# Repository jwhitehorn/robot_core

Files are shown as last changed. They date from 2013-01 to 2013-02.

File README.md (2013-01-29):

## Overview

Open design for a programable real-time robotics controller.

See [Byte Code](https://github.com/jwhitehorn/robot_core/wiki/Byte-Code).

## Status

This project is in a pre-alpha state, or in other words; Robot Core is currently a rough prototype. 
With that said, it's design, function, and features will change drastically as it evolves.

## Hardware & Documentation License

Copyright (c) 2013, [Jason Whitehorn](https://github.com/jwhitehorn) released under the terms of:

[Creative Commons CC-BY-SA 3.0](http://creativecommons.org/licenses/by-sa/3.0/us/)

## Software License

Copyright (c) 2013, [Jason Whitehorn](https://github.com/jwhitehorn) 
All rights reserved.

Redistribution and use in source and binary forms, with or without modification, are permitted provided that the following conditions are met:

* Redistributions of source code must retain the above copyright notice, this list of conditions and the following disclaimer.
* Redistributions in binary form must reproduce the above copyright notice, this list of conditions and the following disclaimer in the documentation and/or other materials provided with the distribution.

THIS SOFTWARE IS PROVIDED BY THE COPYRIGHT HOLDERS AND CONTRIBUTORS "AS IS" AND ANY EXPRESS OR IMPLIED WARRANTIES, INCLUDING, BUT NOT LIMITED TO, THE IMPLIED WARRANTIES OF MERCHANTABILITY AND FITNESS FOR A PARTICULAR PURPOSE ARE DISCLAIMED. IN NO EVENT SHALL THE COPYRIGHT HOLDER OR CONTRIBUTORS BE LIABLE FOR ANY DIRECT, INDIRECT, INCIDENTAL, SPECIAL, EXEMPLARY, OR CONSEQUENTIAL DAMAGES (INCLUDING, BUT NOT LIMITED TO, PROCUREMENT OF SUBSTITUTE GOODS OR SERVICES; LOSS OF USE, DATA, OR PROFITS; OR BUSINESS INTERRUPTION) HOWEVER CAUSED AND ON ANY THEORY OF LIABILITY, WHETHER IN CONTRACT, STRICT LIABILITY, OR TORT (INCLUDING NEGLIGENCE OR OTHERWISE) ARISING IN ANY WAY OUT OF THE USE OF THIS SOFTWARE, EVEN IF ADVISED OF THE POSSIBILITY OF SUCH DAMAGE.

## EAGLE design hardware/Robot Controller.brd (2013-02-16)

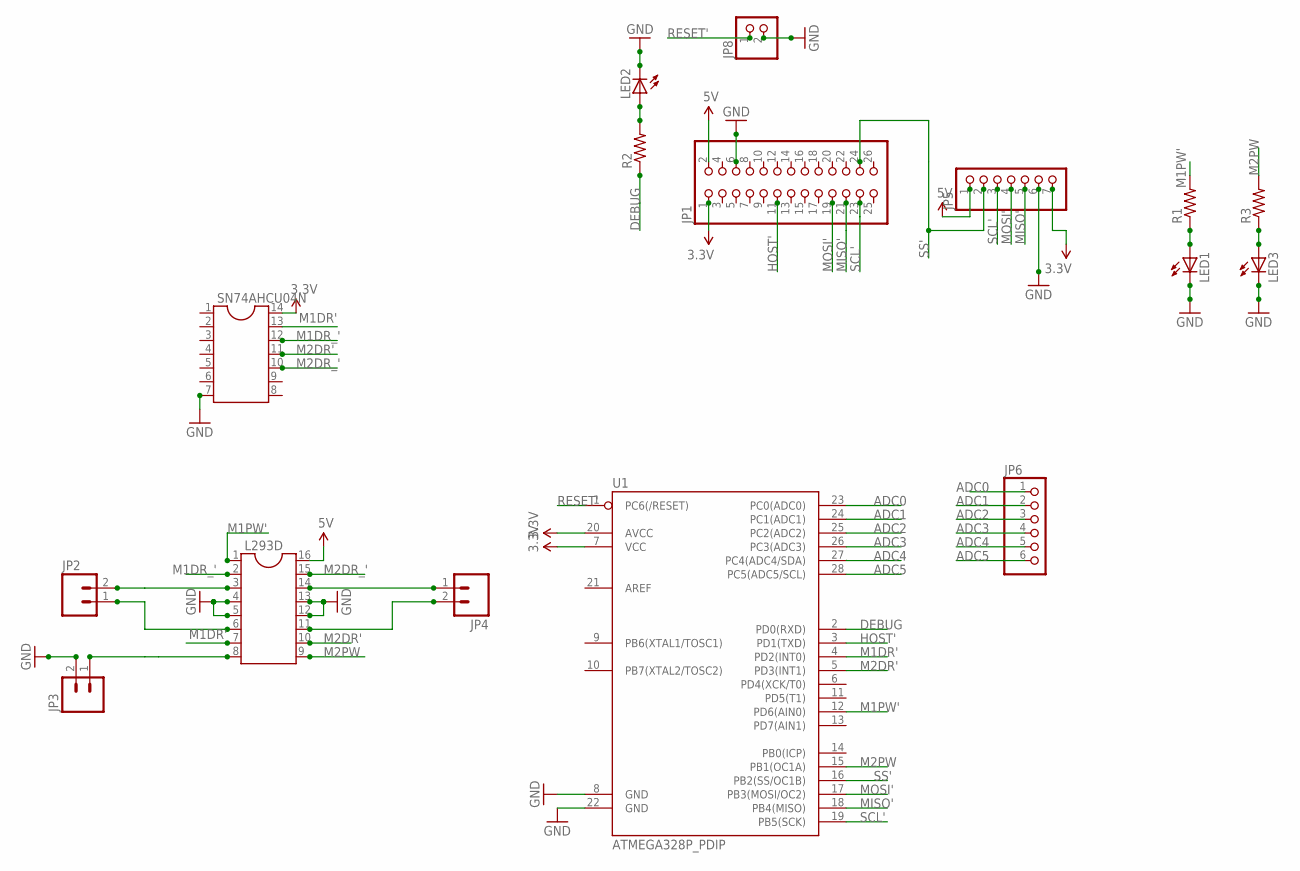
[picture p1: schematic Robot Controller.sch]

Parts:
JP1: PINHD-2X13; 2X13
JP2, JP3, JP4: M025MM; SCREWTERMINAL-5MM-2
JP5: PINHD-1X7; 1X07
JP6: PINHD-1X6; 1X06
JP8: PINHD-1X2; 1X02
L293D: DIL16S; SOCKET-16
LED1, LED2, LED3: LEDSMT1206; 1206
R1, R2, R3: R-US_R3216; R3216
SN74AHCU04N: DIL14S; SOCKET-14
U1: ATMEGA328P_PDIP; DIL28-3

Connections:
3.3V: JP1.1, JP5.7, SN74AHCU04N.14, U1.7 (VCC), U1.20 (AVCC)
5V: JP1.2, JP5.1, L293D.16
ADC0: JP6.1, U1.23 (PC0(ADC0))
ADC1: JP6.2, U1.24 (PC1(ADC1))
ADC2: JP6.3, U1.25 (PC2(ADC2))
ADC3: JP6.4, U1.26 (PC3(ADC3))
ADC4: JP6.5, U1.27 (PC4(ADC4/SDA))
ADC5: JP6.6, U1.28 (PC5(ADC5/SCL))
DEBUG: R2.1, U1.2 (PD0(RXD))
GND: JP1.6, JP3.2, JP5.6, JP8.2, L293D.4, L293D.5, L293D.12, L293D.13, LED1.C, LED2.C, LED3.C, SN74AHCU04N.7, U1.8 (GND), U1.22 (GND)
HOST': JP1.11, U1.3 (PD1(TXD))
M1DR': L293D.7, SN74AHCU04N.13, U1.4 (PD2(INT0))
M1DR_': L293D.2, SN74AHCU04N.12
M1PW': L293D.1, R1.2, U1.12 (PD6(AIN0))
M2DR': L293D.10, SN74AHCU04N.11, U1.5 (PD3(INT1))
M2DR_': L293D.15, SN74AHCU04N.10
M2PW: L293D.9, R3.2, U1.15 (PB1(OC1A))
MISO': JP1.21, JP5.5, U1.18 (PB4(MISO))
MOSI': JP1.19, JP5.4, U1.17 (PB3(MOSI/OC2))
unnamed: LED1.A, R1.1
unnamed: JP2.2, L293D.3
unnamed: JP2.1, L293D.6
unnamed: JP3.1, L293D.8
unnamed: LED3.A, R3.1
unnamed: LED2.A, R2.2
unnamed: JP4.1, L293D.14
unnamed: JP4.2, L293D.11
RESET': JP8.1, U1.1 (PC6(/RESET))
SCL': JP1.23, JP5.3, U1.19 (PB5(SCK))
SS': JP1.24, JP5.2, U1.16 (PB2(SS/OC1B))

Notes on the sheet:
SCL'
MISO'
MOSI'
RESET'
M1PW'
M2PW
M1DR'
M2DR'
M1DR_'
M2DR_'
DEBUG
HOST'
SS'
ADC0
ADC1
ADC2
ADC3
ADC4
ADC5

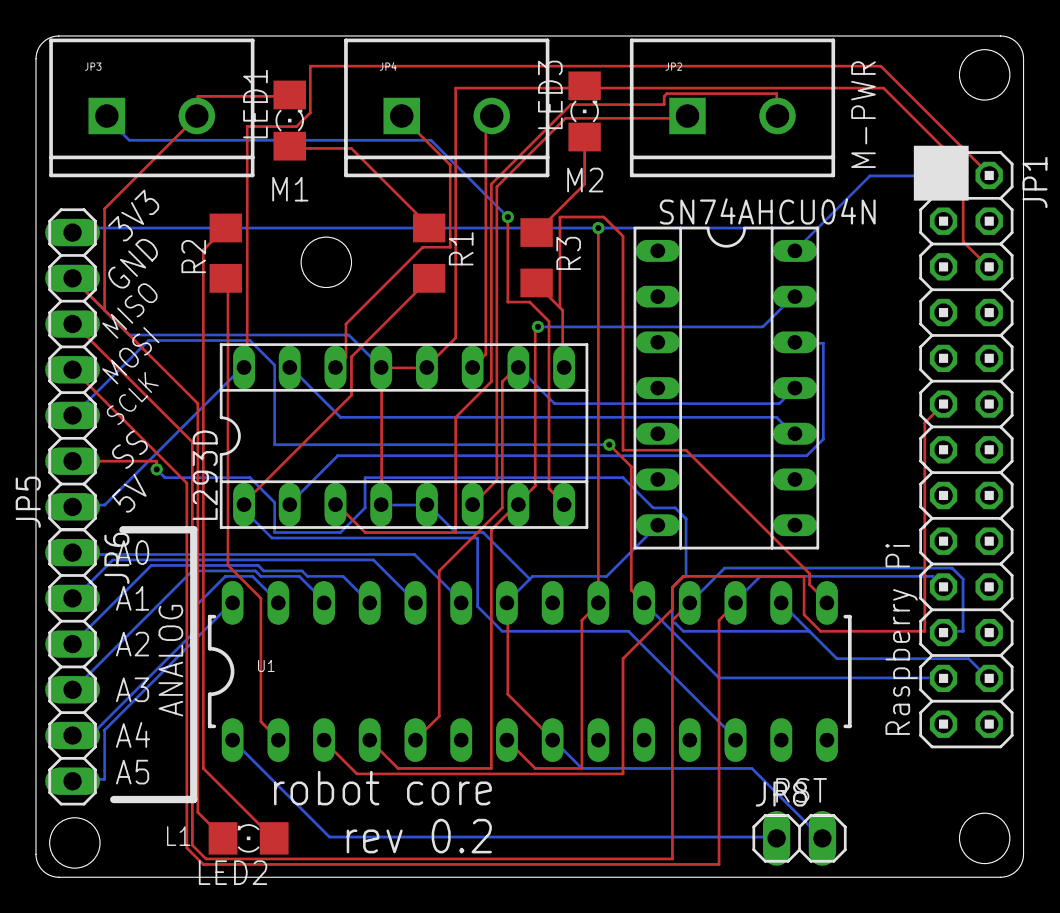
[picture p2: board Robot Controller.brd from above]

Board: 2 copper layers, 54.9 x 46.7 mm, 16 parts (0 on the bottom side), 30 nets.

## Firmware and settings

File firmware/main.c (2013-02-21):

#define F_CPU 8000000UL  // 8 MHz
#include <stdbool.h>
#include <avr/io.h>
#include <inttypes.h>
#include <avr/interrupt.h>
#include <util/delay.h>
#include "spi.h"
#include "helpers.h"

//SPI
#define CTRL_PORT   DDRB 
#define DATA_PORT   PORTB 
#define CLK_PIN     PB7 
#define DI_PIN      PB5 
#define DO_PIN      PB6 

//registers
#define REG_M1PW   0x01  //motor 1, pulse width
#define REG_M2PW   0x02  //motor 2, pulse width
#define REG_M1DR   0x03  //motor 1, direction
#define REG_M2DR   0x04  //motor 2, direction
#define ADC1       0x05  //ADC 1
#define GPIO1      0x06  //GPIO 1

//op codes
#define REGW       0x01
#define CLRH       0x02
#define RIFEQ      0x03
#define RIFLT      0x04
#define MODE       0x05
#define RIFGT      0x06


/*

Have the main run-loop of the app just poll various pins and check various registers based on
a table that the "processCommand" function esthablishes via direction of the host.

The refactored commands might look like:

REGWIFEQ w, x, y, z - writes x to register w if register y is equal to z
REGWIFLT w, x, y, z - writes x to register w if register y is less than z
REGWIFGT w, x, y, z - writes x to register w if register y is greater than z

This will mean we'll need "registers" for each GPIO & analog pin.

Later we can add timers as registers too.
  
*/


#define MAX_COMMAND_LEN 10
char command_buffer[MAX_COMMAND_LEN] = {0};
int command_length = 0;


#define MAX_TABLE_SIZE 10
char table[MAX_TABLE_SIZE][MAX_COMMAND_LEN];
int table_size = 0;


void clearBuffer(){
    command_length = 1; //since we're ignoring the first byte, just skip it and assume 0
    for(int i = 0; i != MAX_COMMAND_LEN; i++) command_buffer[i] = 0x00; //clear buffer
}

void storeCommandInTable(char *command, int length){
  if(table_size < MAX_TABLE_SIZE){
    int table_entry = table_size++;
    for(int i = 0; i != length || MAX_COMMAND_LEN; i++){
      table[table_entry][i] = command[i];
    }
  }
}

int compareRegister(int reg, int value){
  int valueRead = 0;
  if(reg == ADC1){
    uint16_t adc = ReadADC(0);
    valueRead = (adc >> 2);
  }else if(reg == GPIO1){
    valueRead = readPin(GPIO1_PIN);
  }else{
    return -2;
  } 
  if(valueRead < value){
    return -1;
  }else if(valueRead == value){
    return 0;
  }
  return 1;
}

bool processCommand(char *command, int length, bool store){
  if(length < 2) return false;    //no command is this short
  
  int op_code = command[1];  //first byte of op-code isn't implemented yet

  if(op_code == REGW){
    /*
    * REGW - Register Write - Writes byte 4 to the register specified in byte 3
    * Command length: 4 bytes
    */
    if(length >= 4){
      int reg = command[2];
      int byte = command[3];
      if(reg == 0x00){              //0x00 is undocumented, used for debugging. It echoes the received bit on the host pin.
        if(byte > 0){
          outputHigh(HOST_PIN);
        }else{
          outputLow(HOST_PIN);
        }
      }else if(reg == REG_M1PW){
        OCR0A = byte;
      }else if(reg == REG_M2PW){
        OCR1A = byte;
      }else if(reg == REG_M1DR){
        if(byte > 0){
          outputHigh(M1DR_PIN);
        }else{
          outputLow(M1DR_PIN);
        }
      }else if(reg == REG_M2DR){
        if(byte > 0){
          outputHigh(M2DR_PIN);
        }else{
          outputLow(M2DR_PIN);
        }
      }
      return true;
    }//else, wait for more bytes...
  }else if(op_code == CLRH){
    /*
    * CLRH - Clear Host Pin - Resets the host pin. E.g., it sets it low.
    * Command length: 2 bytes
    */
    outputLow(HOST_PIN);
    return true;
  }else if(op_code == RIFLT || op_code == RIFGT || op_code == RIFEQ){
    /*
    * RIFEQ x, y - raise the host pin if register x is equal to y (binary pins will have their registers either be 0x00 or 0x01)
    * RIFLT x, y - raise the host pin if register x is less than y
    * RIFGT x, y - raise the host pin if register x is greater than y
    * Command Length: 4 bytes
    */
    if(length >= 4){
      if(store){
        storeCommandInTable(command, length);
      }else{
        int reg = command[2];
        int value = command[3];
        int result = compareRegister(reg, value);
        if(op_code == RIFLT && result == -1){
          outputHigh(HOST_PIN);
        }else if(op_code == RIFGT && result == 1){
          outputHigh(HOST_PIN);
        }else if(op_code == RIFEQ && result == 0){
          outputHigh(HOST_PIN);
        }
      }
      return true;
    } 
  }else if(op_code == MODE){
    if(length >= 4){
      int reg = command[2];
      int mode = command[3];
      if(reg == GPIO1 && mode == 0x00){
        setInput(GPIO1_PIN); 
      }else if(reg == GPIO1 && mode == 0x01){
        setOutput(GPIO1_PIN);
      }
      return true;
    }
  }else{ //unknown op code
    return true; //??
  }
  return false;
}

void processCommandBuffer(){
  bool result = processCommand(command_buffer, command_length, true);
  if(result){
    clearBuffer();
  }
}

ISR(SPI_VECTOR){
  int byte = spiReceived() / 2;

  if(command_length < MAX_COMMAND_LEN){ //do not allow overflow, no command should be this long
    command_buffer[command_length++] = byte;
    processCommandBuffer();
  }else{
    clearBuffer();
  } 
}

int main(void){
  setOutput(M1PW_PIN);
  TCCR0B = 0;                     // stop timer 0
  TCCR0A = (1<<WGM00)|(1<<WGM01); // select fast pwm mode 3
  TCCR0A |= (1<<COM0A1);          //Clear OC0A on Compare Match when up-counting. Set OC0A on Compare Match when down-counting.
  OCR0A = 0x00;                   //duty cycle
  TCCR0B |= (1<<CS00);            // no prescaling

  setOutput(M2PW_PIN);
  TCCR1B = 0;
  TCCR1A = (1<<WGM00);
  TCCR1A |= (1<<COM1A1);
  OCR1A = 0x00;
  TCCR1B |= (1<<CS00);
  
  setOutput(HOST_PIN);
  outputLow(HOST_PIN);

  // Select Vref=AVcc
  ADMUX |= (1<<REFS0);
  //set prescaller to 128 and enable ADC 
  ADCSRA |= (1<<ADPS2)|(1<<ADPS1)|(1<<ADPS0)|(1<<ADEN);  

  //Setup SPI/USI
  setupSpi();

  clearBuffer();
  sei();
  
  setOutput(M1DR_PIN);
  outputLow(M1DR_PIN);
  setOutput(M2DR_PIN);
  outputLow(M2DR_PIN);

  //by default, let's set GPIO pins to be inputs
  setInput(GPIO1_PIN);
  
  //blink to signal ready...
  setOutput(DEBUG_PIN);
  outputHigh(DEBUG_PIN);
  sleep(1000);
  outputLow(DEBUG_PIN);
/*
  table_size = 1;
  table[0][0] = 0x00;
  table[0][1] = 0x04;
  table[0][2] = 0x06;
  table[0][3] = 0x01; 
*/  
  //ready!
  while(1){
    for(int i = 0; i != table_size; i++){
      processCommand(table[i], MAX_COMMAND_LEN, false); 
    }
  }
}

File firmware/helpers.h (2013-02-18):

//Helper file to abstract away platform specifics.

//Suport for both attiny and atmega devices
#ifdef PORTA
#define ATTINY
#define SPI_VECTOR USI_OVERFLOW_vect
#else
#define ATMEGA
#define SPI_VECTOR SPI_STC_vect
#define USIDR SPDR
#define USISR SPDR
#endif

//ATtiny doesn't support SPI per se, but it can use USI as SPI... let's abstract that...
int spiReceived(){
  #ifdef ATTINY
  int byte = USIDR / 2;
  USISR = (1<<USIOIF);
  USIDR = byte;
  return byte;
  #else
  SPDR = 0x00;  
  return SPDR; 
  #endif
}

void setupSpi(){
  #ifdef ATTINY
  USICR = _BV(USIOIE) | _BV(USIWM0) | _BV(USICS0) | _BV(USICS1);
  USISR = (1<<USIOIF);
  #else
  setup_spi(SPI_MODE_1, SPI_MSB, SPI_INTERRUPT, SPI_SLAVE);
  #endif
}


//General helpers:
#define __output_low(port,pin, portdir, hwpin) port &= ~(1<<pin)    
#define __output_high(port,pin, portdir, hwpin) port |= (1<<pin)
#define __set_input(port, pin, portdir, hwpin) portdir &= ~(1<<pin)
#define __set_output(port, pin, portdir, hwpin) portdir |= (1<<pin)
#define __read_pin(port, pin, portdir, hwpin) hwpin & (1<<pin)

#define outputLow(pin) __output_low(pin)
#define outputHigh(pin) __output_high(pin)
#define setInput(pin) __set_input(pin)
#define setOutput(pin) __set_output(pin)
#define readPin(pin) __read_pin(pin)

#define sleep _delay_ms

//Pins:
#define HOST_PIN    PORTD, PD1, DDRD, PINA
#define DEBUG_PIN   PORTD, PD0, DDRD, PINA
#define M1DR_PIN    PORTD, PD2, DDRD, PIND
#define M2DR_PIN    PORTD, PD3, DDRD, PIND
#define M1PW_PIN    PORTD, PD6, DDRD, PIND
#define M2PW_PIN    PORTB, PB1, DDRB, PINB
#define ADC1_PIN    PORTC, PC1, DDRC, PINC
#define GPIO1_PIN   PORTD, PD7, DDRD, PIND

uint16_t ReadADC(uint8_t ADCchannel){
  //select ADC channel with safety mask
  ADMUX = (ADMUX & 0xF0) | (ADCchannel & 0x0F);
  //single conversion mode
  ADCSRA |= (1<<ADSC);
  // wait until ADC conversion is complete
  while( ADCSRA & (1<<ADSC) );
  return ADC;
}

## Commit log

2013-01-29 added hardware
    [Robot Controller.brd, Robot Controller.sch]
2013-01-29 added a host pin
    [Robot Controller.brd, Robot Controller.sch]
2013-01-30 switch to using interrupts... a little better luck getting the firmware to take commands
2013-01-30 thinking out how motor direction will be controlled
    [Robot Controller.brd, Robot Controller.sch]
2013-01-30 tweak hardware design
    [Robot Controller.brd, Robot Controller.sch]
2013-01-30 abstract the debug pin
2013-01-30 fixed host pin stupidity
    [main.c]
2013-01-31 change host pin
    [Robot Controller.brd, Robot Controller.sch]
2013-01-31 setup timer 1
2013-01-31 implement motor 2
2013-01-31 got motor 2 working!!!
2013-01-31 update hardware for second motor
    [Robot Controller.brd, Robot Controller.sch]
2013-01-31 ideas around master/slave robot cores
    [Robot Controller.brd, Robot Controller.sch]
2013-02-01 WIP dev board
    [Robot Controller.brd, Robot Controller.sch]
2013-02-01 silkscreen work
    [Robot Controller.brd, Robot Controller.sch]
2013-02-02 tighten up PCB
    [Robot Controller.brd, Robot Controller.sch]
2013-02-02 motor direction control
2013-02-05 temp fix to crazy bug
    [main.c]
2013-02-05 fixed previous bug by explicitly initializing the command buffer to 0
    [main.c]
2013-02-05 working on cleaning up schematic
    [Robot Controller.brd, Robot Controller.sch]
2013-02-06 need ADC, upgrading to ATmega328
    [Robot Controller.brd, Robot Controller.sch]
2013-02-06 rough routing
    [Robot Controller.brd]
2013-02-07 include SPI helper
2013-02-10 fixed helpers to make them less broken
    [helpers.h]
2013-02-10 significant amount of less-broken
    [helpers.h, main.c]
2013-02-10 SPI slave work on the mega
2013-02-11 WIP ATmega328 hardware
    [Robot Controller.brd, Robot Controller.sch]
2013-02-11 update connections to match todays progress
    [Robot Controller.brd, Robot Controller.sch]
2013-02-13 WIP adc
2013-02-14 more WIP adc
2013-02-14 WIP hardware
    [Robot Controller.brd, Robot Controller.sch]
2013-02-15 fix outline
    [Robot Controller.brd]
2013-02-16 change name to be on tPlace, not tStop :-(
    [Robot Controller.brd]
2013-02-16 more work on rev0.2 hardware
    [Robot Controller.brd, Robot Controller.sch]

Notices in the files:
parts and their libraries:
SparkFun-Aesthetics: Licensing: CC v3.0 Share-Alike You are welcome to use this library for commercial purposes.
